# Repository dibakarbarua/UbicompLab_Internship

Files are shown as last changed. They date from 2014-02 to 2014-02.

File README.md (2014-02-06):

raspberrypi-sensing
===================

Summer Internship, 2013. MUC Lab- IIIT Delhi.

Hey Guys

This is my Repository for my Summer Project which I did at the
Mobile and Ubiquitous Computing Group, IIIT Delhi in Summer, 2013.
I interfaced various sensors on various protocols on the Raspberry Pi
and made an extension board for the fronend to a Cloud-based Sensor
data acquisition system called SENSORACT.

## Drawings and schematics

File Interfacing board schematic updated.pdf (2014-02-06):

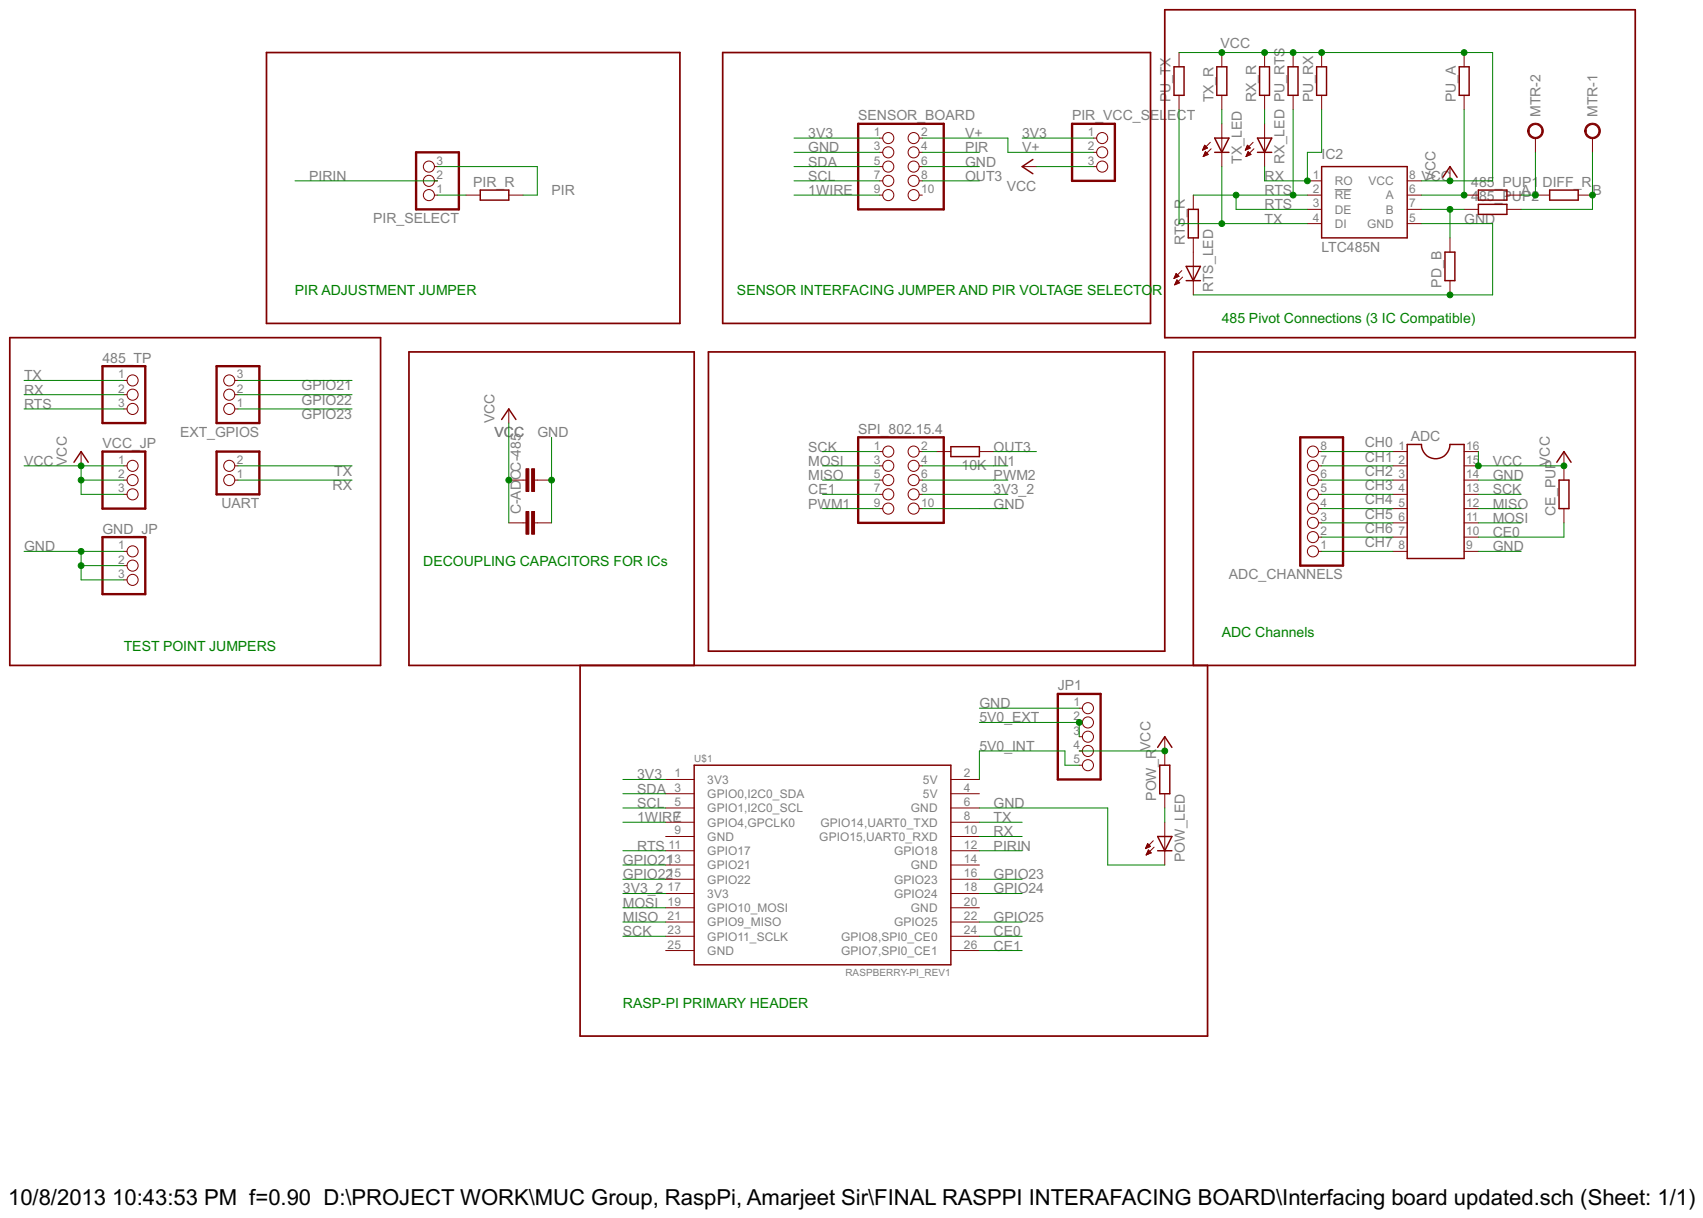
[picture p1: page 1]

485 Pivot Connections (3 IC Compatible)

RASP-PI PRIMARY HEADER

10/8/2013 10:43:53 PM f=0.90 D:\PROJECT WORK\MUC Group, RaspPi, Amarjeet Sir\FINAL RASPPI INTERAFACING BOARD\Interfacing board updated.sch (Sheet: 1/1)

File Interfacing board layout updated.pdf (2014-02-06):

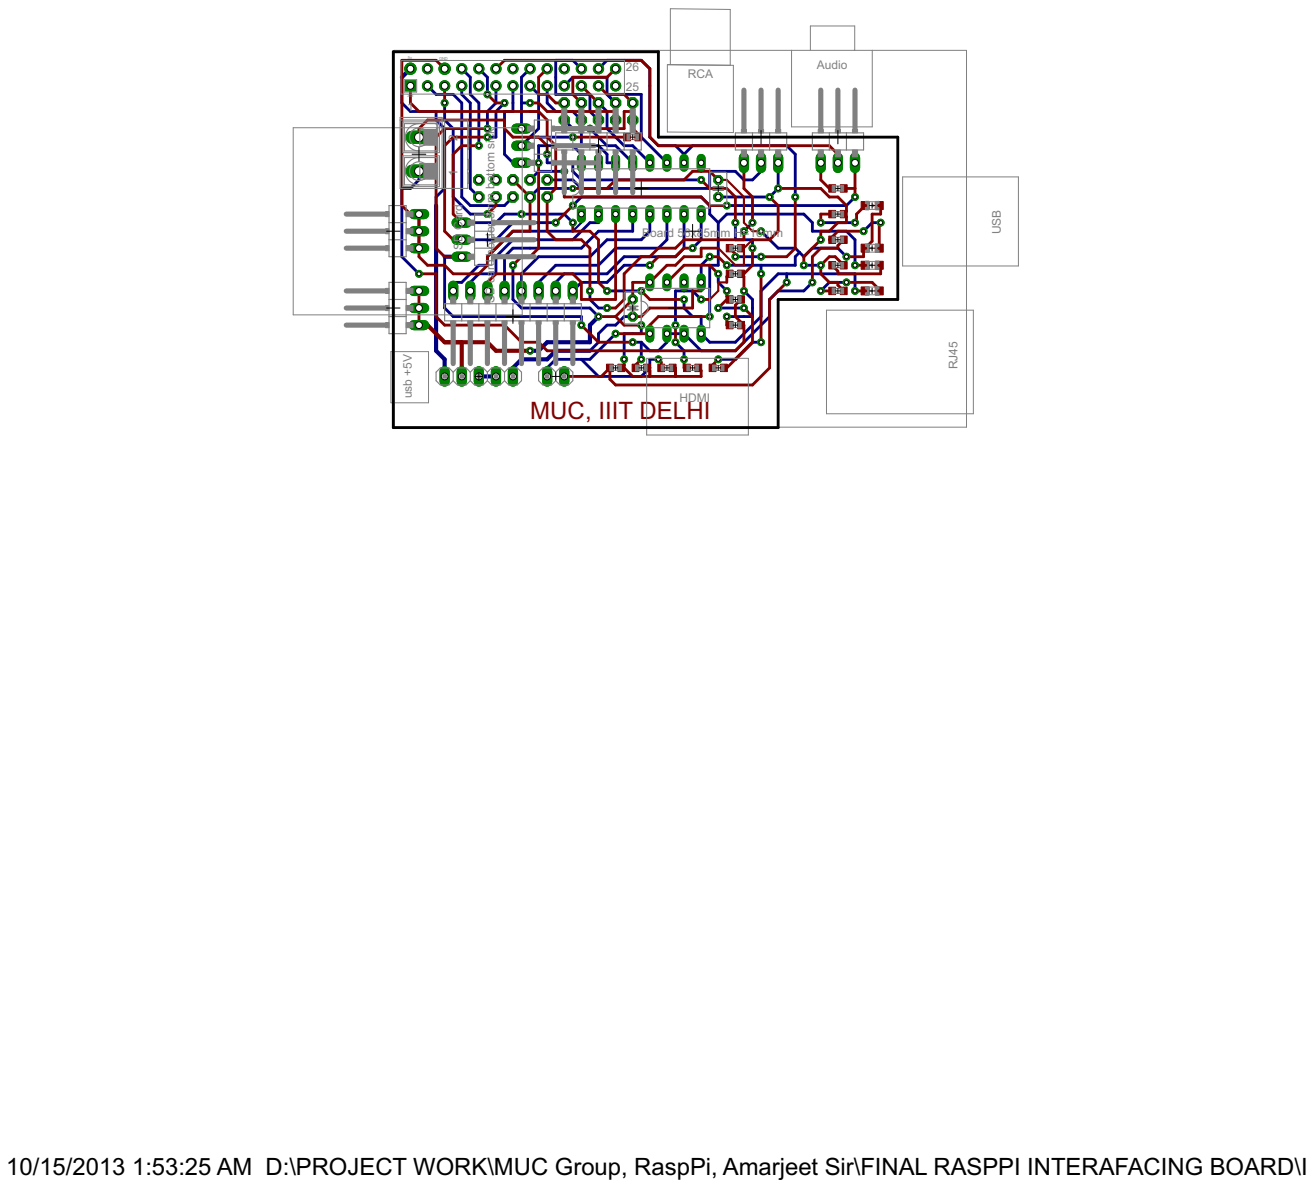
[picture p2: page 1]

SD card holder 5mm bottom sick

10/15/2013 1:53:25 AM D:\PROJECT WORK\MUC Group, RaspPi, Amarjeet Sir\FINAL RASPPI INTERAFACING BOARD\Interfacing board updated.brd

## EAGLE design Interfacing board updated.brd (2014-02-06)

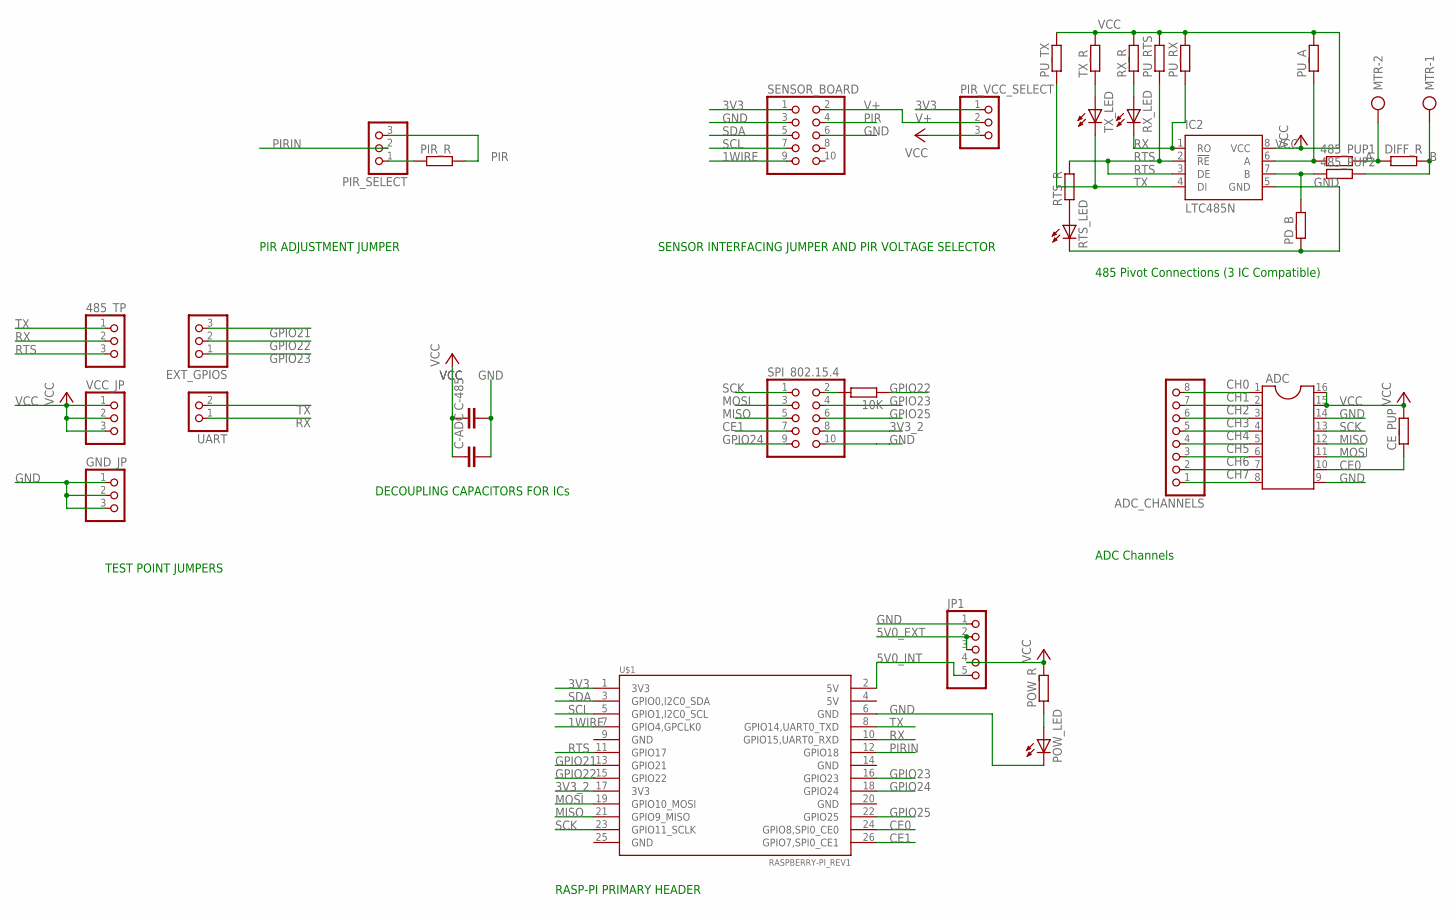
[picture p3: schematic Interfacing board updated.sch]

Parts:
10K, 485_PUP1, 485_PUP2: R-EU_R0603; R0603
485_TP: PINHD-1X3/90; 1X03/90
ADC: DIL16
ADC_CHANNELS: PINHD-1X8/90; 1X08/90
C-485: C-EU025-025X050; C025-025X050
C-ADC: C-EU025-025X050; C025-025X050
CE_PUP: R-EU_R0603; R0603
DIFF_R: R-EU_R0603; R0603
EXT_GPIOS: PINHD-1X3/90; 1X03/90
GND_JP: PINHD-1X3/90; 1X03/90
IC2: LTC485N; DIL08
JP1: PINHD-1X5; 1X05
MTR: AK500/2-H
PD_B: R-EU_R0603; R0603
PIR_R: R-EU_R0603; R0603
PIR_SELECT: PINHD-1X3/90; 1X03/90
PIR_VCC_SELECT: PINHD-1X3/90; 1X03/90
POW_LED: LEDCHIPLED_0805; CHIPLED_0805
POW_R: R-EU_R0603; R0603
PU_A: R-EU_R0603; R0603
PU_RTS: R-EU_R0603; R0603
PU_RX: R-EU_R0603; R0603
PU_TX: R-EU_R0603; R0603
RTS_LED: LEDCHIPLED_0805; CHIPLED_0805
RTS_R: R-EU_R0603; R0603
RX_LED: LEDCHIPLED_0805; CHIPLED_0805
RX_R: R-EU_R0603; R0603
SENSOR_BOARD: PINHD-2X5/90; 2X05/90
SPI_802.15.4: PINHD-2X5/90; 2X05/90
TX_LED: LEDCHIPLED_0805; CHIPLED_0805
TX_R: R-EU_R0603; R0603
U$1: RASPBERRY-PI_REV1
UART: PINHD-1X2; 1X02
VCC_JP: PINHD-1X3/90; 1X03/90

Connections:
1WIRE: SENSOR_BOARD.9, U$1.7 (GPIO4,GPCLK0)
3V3: PIR_VCC_SELECT.1, SENSOR_BOARD.1, U$1.1 (3V3)
3V3_2: SPI_802.15.4.8, U$1.17 (3V3)
5V0_EXT: JP1.2, JP1.3
5V0_INT: JP1.5, U$1.2 (5V)
A: 485_PUP1.2, DIFF_R.1, MTR.2
B: 485_PUP2.2, DIFF_R.2, MTR.1
CE0: ADC.10, CE_PUP.1, U$1.24 (GPIO8,SPI0_CE0)
CE1: SPI_802.15.4.7, U$1.26 (GPIO7,SPI0_CE1)
CH0: ADC.1, ADC_CHANNELS.8
CH1: ADC.2, ADC_CHANNELS.7
CH2: ADC.3, ADC_CHANNELS.6
CH3: ADC.4, ADC_CHANNELS.5
CH4: ADC.5, ADC_CHANNELS.4
CH5: ADC.6, ADC_CHANNELS.3
CH6: ADC.7, ADC_CHANNELS.2
CH7: ADC.8, ADC_CHANNELS.1
GND: ADC.9, ADC.14, C-485.2, C-ADC.2, GND_JP.1, GND_JP.2, GND_JP.3, IC2.5 (GND), JP1.1, PD_B.1, POW_LED.C, RTS_LED.C, SENSOR_BOARD.3, SENSOR_BOARD.6, SPI_802.15.4.10, U$1.6 (GND)
GPIO21: EXT_GPIOS.3, U$1.13 (GPIO21)
GPIO22: 10K.1, EXT_GPIOS.2, U$1.15 (GPIO22)
GPIO23: EXT_GPIOS.1, SPI_802.15.4.4, U$1.16 (GPIO23)
GPIO24: SPI_802.15.4.9, U$1.18 (GPIO24)
GPIO25: SPI_802.15.4.6, U$1.22 (GPIO25)
MISO: ADC.12, SPI_802.15.4.5, U$1.21 (GPIO9_MISO)
MOSI: ADC.11, SPI_802.15.4.3, U$1.19 (GPIO10_MOSI)
unnamed: 485_PUP1.1, IC2.6 (A), PU_A.1
unnamed: 485_PUP2.1, IC2.7 (B), PD_B.2
unnamed: PIR_R.1, PIR_SELECT.1
unnamed: POW_LED.A, POW_R.1
unnamed: RTS_LED.A, RTS_R.1
unnamed: 10K.2, SPI_802.15.4.2
PIR: PIR_R.2, PIR_SELECT.3, SENSOR_BOARD.4
PIRIN: PIR_SELECT.2, U$1.12 (GPIO18)
RTS: 485_TP.3, IC2.2 (!RE), IC2.3 (DE), PU_RTS.1, RTS_R.2, U$1.11 (GPIO17)
RX: 485_TP.2, IC2.1 (RO), PU_RX.1, RX_LED.C, U$1.10 (GPIO15,UART0_RXD), UART.1
RX_R: RX_LED.A, RX_R.1
SCK: ADC.13, SPI_802.15.4.1, U$1.23 (GPIO11_SCLK)
SCL: SENSOR_BOARD.7, U$1.5 (GPIO1,I2C0_SCL)
SDA: SENSOR_BOARD.5, U$1.3 (GPIO0,I2C0_SDA)
TX: 485_TP.1, IC2.4 (DI), PU_TX.1, TX_LED.C, U$1.8 (GPIO14,UART0_TXD), UART.2
TX_R: TX_LED.A, TX_R.1
V+: PIR_VCC_SELECT.2, SENSOR_BOARD.2
VCC: ADC.15, ADC.16, C-485.1, C-ADC.1, CE_PUP.2, IC2.8 (VCC), JP1.4, PIR_VCC_SELECT.3, POW_R.2, PU_A.2, PU_RTS.2, PU_RX.2, PU_TX.2, RX_R.2, TX_R.2, VCC_JP.1, VCC_JP.2, VCC_JP.3

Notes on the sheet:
ADC Channels
485 Pivot Connections (3 IC Compatible)
SENSOR INTERFACING JUMPER AND PIR VOLTAGE SELECTOR
PIR ADJUSTMENT JUMPER
DECOUPLING CAPACITORS FOR ICs
TEST POINT JUMPERS
RASP-PI PRIMARY HEADER

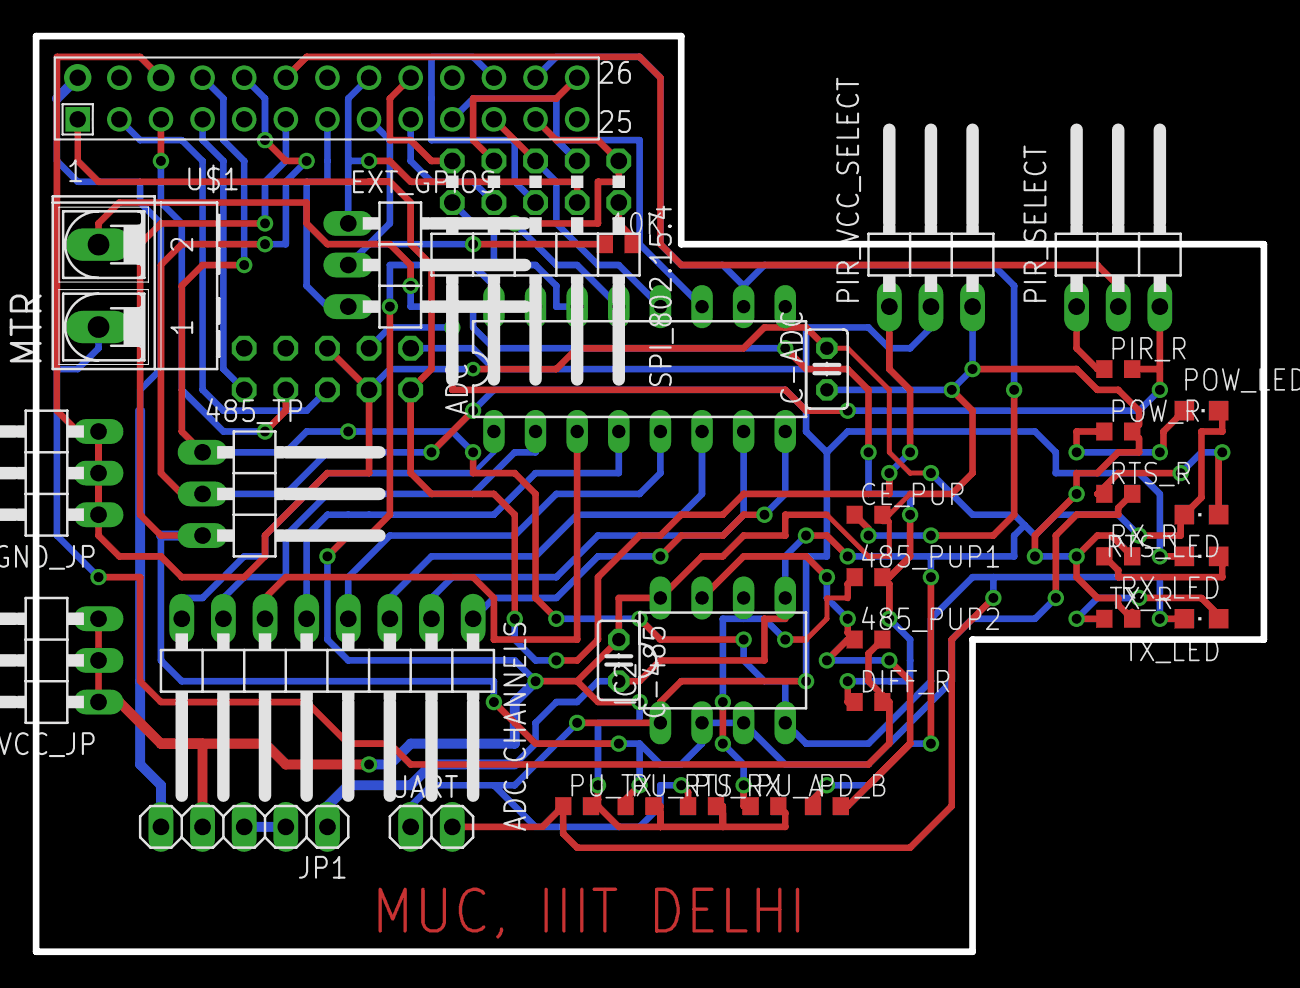
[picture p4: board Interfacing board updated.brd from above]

Board: 2 copper layers, 74.9 x 55.9 mm, 36 parts (1 on the bottom side), 43 nets.

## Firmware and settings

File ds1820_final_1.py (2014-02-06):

import os
import glob
import time
os.system('modprobe w1-gpio')
os.system('modprobe w1-therm')
base_dir = '/sys/bus/w1/devices/'
device_folder = glob.glob(base_dir + '28*')[0]
device_file = device_folder + '/w1_slave'
def read_temp_raw():
    f = open(device_file, 'r')
    lines = f.readlines()
    f.close()
    return lines
def read_temp():
    lines = read_temp_raw()
    while lines[0].strip()[-3:] != 'YES':
        time.sleep(0.2)
        lines = read_temp_raw()
    equals_pos = lines[1].find('t=')
    if equals_pos != -1:
        temp_string = lines[1][equals_pos+2:]
        temp_c = float(temp_string) / 1000.0
        temp_f = temp_c * 9.0 / 5.0 + 32.0
        return temp_c, temp_f
while True:
    print(read_temp())
    time.sleep(1)

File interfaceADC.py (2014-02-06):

#!/usr/bin/python
#INTERFACING ADC MCP3008- Dibakar Barua
import RPi.GPIO as GPIO
import time
GPIO.setmode(GPIO.BOARD)
GPIO.setwarnings(False)

mosi = 19
miso = 21
sck = 23
cs = 7

GPIO.setup(mosi,GPIO.OUT)
GPIO.setup(miso,GPIO.IN)
GPIO.setup(sck,GPIO.OUT)
GPIO.setup(cs,GPIO.OUT)

def readadc (adcch):
	GPIO.output(cs, True)
	GPIO.output(sck, False) # start clock low
	GPIO.output(cs, False)	

	dataout = adcch
	# to set start bit and SGL bit and D2, D1, D0 as per adcch value
	dataout |= 0x18
	# only 5 control bits are needed 
	dataout <<= 3 
	for i in range(5):
		if ((dataout & 0x80) != 0):
			GPIO.output(mosi,True)
		else: 
			GPIO.output(mosi,False)
		dataout <<= 1
		GPIO.output(sck, True)
		GPIO.output(sck, False)	

	#initalize data to be read from adc
	datain = 0
	for i in range(12):
		GPIO.output(sck, True)
		GPIO.output(sck, False)
		datain <<= 1
		if(GPIO.input(miso)):
			datain |= 0x1
	
	GPIO.output(cs, True)
	#drop empty and null bits
	datain >>= 1 
	return datain

#main program
#infinite loop
while True:
	#read channel 0 and print value continuously
	adcval = readadc(0)
	print "adc value =" 	
	print(adcval)
	#give delay
	time.sleep(1)

	
